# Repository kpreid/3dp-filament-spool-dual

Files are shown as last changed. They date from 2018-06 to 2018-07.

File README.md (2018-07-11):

Modification of [Unlockable loose Filament Spool](https://www.thingiverse.com/thing:1986210) which holds two filaments, thus allowing two small samples or leftovers to be held in the same volume as the original design.

## Usage

### Printing

Do not print `_Original_Fork.stl`; it is the original one-slot model, which is only included because `Filament_Spool_Dual_Fork.scad` needs it to generate the modification.

Print:

* 2 copies of `Filament_Spool_Disk.stl`.
* 5 copies of `Filament_Spool_Dual_Fork.scad` (use OpenSCAD to generate the `.stl` file).
* 10 copies of `Filament_Spool_Spike.stl` (each fork now requires two).

Or if you are "upgrading" an existing spool of the original design, print 5 new forks and 5 spikes.

### Assembly

Same as original except for the extra spikes, but this is my writeup of the details:

1. I had to clean the filament holding holes with a 5/64" (about 2 mm) drill bit — slightly smaller would be a better close fit, but this size is usable.

2. Press two spikes onto the hexagonal posts on each fork. Note the asymmetry of the spike — one way will line up nicely with the fixed center spike and the other will not.

3. Press the assembled forks into your choice of notch in the **flat side** of the disk.

4. Put the other disk on top of the forks and press it all together.

5. Gently push each fork's two locking pins towards the hub to make sure the tabs are locked rather than still compressed by the hole.

## License

Copyright 2018 Kevin Reid <kpreid@switchb.org>, except as noted below.

This work is licensed under a <a rel="license" href="https://creativecommons.org/licenses/by/3.0/">Creative Commons Attribution 3.0 International License</a>.

The files `Filament_Spool_Disk.stl`, `Filament_Spool_Spike.stl`, and `_Origimal_Fork.stl` were created by Christoph Laimer (see https://www.thingiverse.com/thing:1986210) and published under the same license.

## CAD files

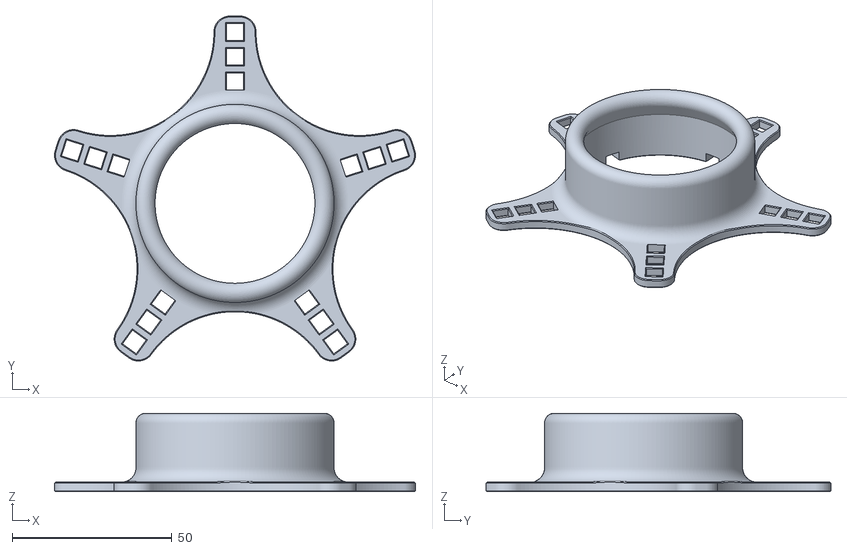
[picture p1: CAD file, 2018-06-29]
Filament_Spool_Disk.stl
113.0 x 108.0 x 24.6

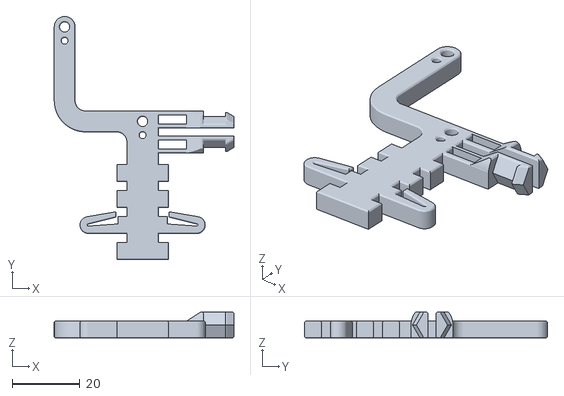
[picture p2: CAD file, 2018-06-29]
_Original_Fork.stl
53.2 x 72.0 x 7.70

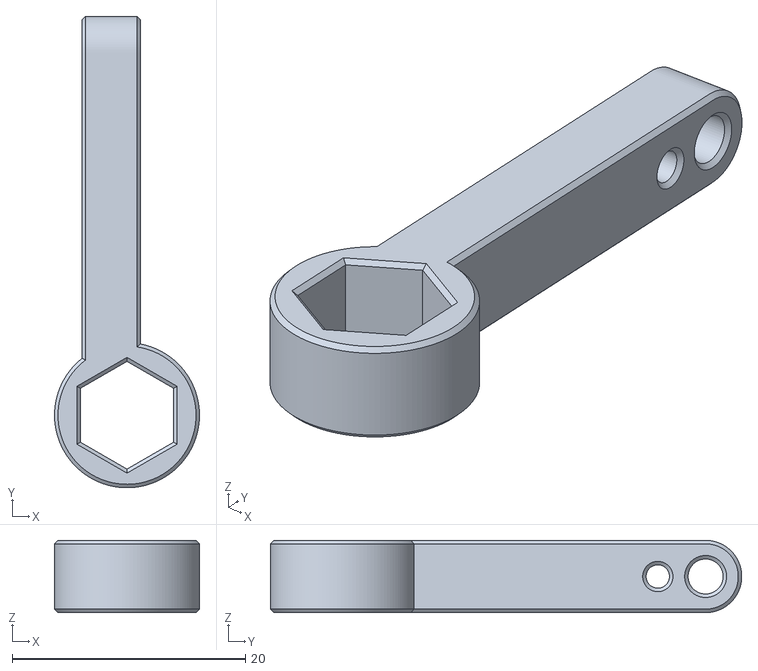
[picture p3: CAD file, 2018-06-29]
Filament_Spool_Spike.stl
12.4 x 40.4 x 6.20

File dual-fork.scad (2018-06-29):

main();
//fixed_spike();

module main() {
    two_pivot();
    fixed_spike();
}

module two_pivot() {
    pivot_half();
    mirror([1, 0, 0]) pivot_half();
}

// The half of the fork which has the pivot.
module pivot_half() {
    intersection() {
        centerline_zeroed();
        
        translate([0, 0, -500])
        cube([1000, 1000, 1000]);
    }
}

// Fork's non-pivoting spike, modified to have a double fillet and translated to be on centerline.
module fixed_spike() {
    fixed_spike_half();
    mirror([1, 0, 0]) fixed_spike_half();
}

// Fork's non-pivoting spike, cut from the rest and translated to be on centerline.
module fixed_spike_half() {
    // Have checked this translation closely.
    translate([-3.1, 0, 0]) 
    intersection() {
        original();
        
        // Cut off the rest of the fork, keeping only the fillet.
        translate([0, 71.5, -500])
        cube([10, 1000, 1000]);
    }
}

// Fork translated so it is centered around the x axis.
module centerline_zeroed() {
    translate([-26.18, 0, 0])
    original();
}

module original() {
    import("Filament_Spool_Fork.stl", convexity=8);
}

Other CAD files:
Filament_Spool_Dual_Fork.scad

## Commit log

2018-06-29 Initial commit with original files and documentation but no implementation.
    [Filament_Spool_Disk.stl, Filament_Spool_Fork.stl, Filament_Spool_Spike.stl]
2018-06-29 Design the fork.
    [dual-fork.scad]
2018-07-03 Rename files to reduce confusion.
    [Filament_Spool_Dual_Fork.scad, _Original_Fork.stl]
2018-07-11 Fix drill bit size and clarify print instruction.
